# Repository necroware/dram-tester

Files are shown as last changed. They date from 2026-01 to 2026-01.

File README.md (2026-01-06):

# 4164 / 41256 DRAM Tester

This is a simple DRAM tester for 4164 and 41256 DRAM chips. It writes and reads
various patterns to verify the integrity of the memory chips. During the the
test red an green LEDs blink alternatively to indicate that the test is running.
If an error was detected, the the red LED will stay on permanently. If the chip
passed the test, the green LED will stay on. With JP1 closed, the tester will
expect a 4164 chip, with JP1 open, it will expect a 41256 chip.

## Why do we need this?

When working with vintage computers, it's common to encounter faulty DRAM chips.
This tester helps to quikly identify bad chips. There is no particular reason
why I decided to make this tester. There are already many similar designs, but
the ones I found were either too slow, or didn't work for me. So I decided to
learn a bit more about DRAMs and make my own tester which is fast and simple.

## Bill of Materials
- Arduino Nano or compatible board
- DIP-16 ZIF socket for 4164/41256 DRAM chips
- 2x 330 Ohm resistors (for LEDs)
- 2x LEDs (red and green)
- 22-100µF capacitor (for power supply stabilization)
- 2x1 2.54mm jumper (for JP1)

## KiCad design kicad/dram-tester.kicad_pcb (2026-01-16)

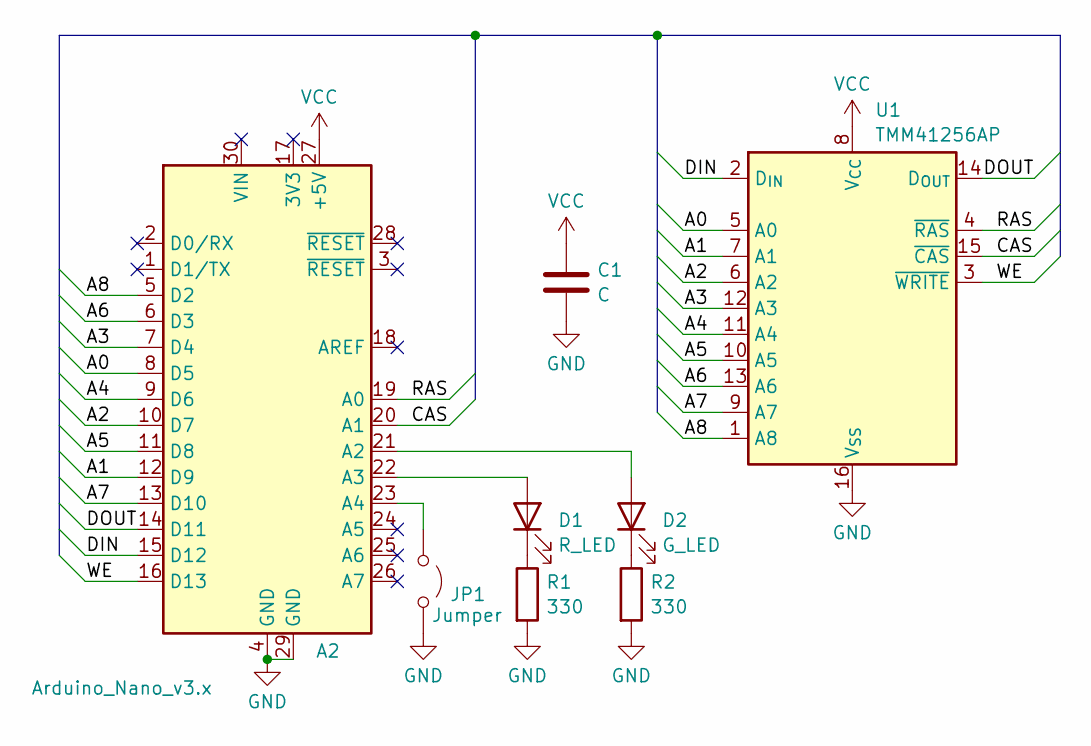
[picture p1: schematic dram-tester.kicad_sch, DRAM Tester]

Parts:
A2: Arduino_Nano_v3.x; Arduino_Nano
C1: C; C_Disc_D3.4mm_W2.1mm_P2.50mm
D1: R_LED; LED_D3.0mm
D2: G_LED; LED_D3.0mm
JP1: Jumper; PinHeader_1x02_P2.54mm_Vertical
R1, R2: 330; R_Axial_DIN0207_L6.3mm_D2.5mm_P10.16mm_Horizontal
U1: TMM41256AP; DIP_Socket-16_W4.3mm_W5.08mm_W7.62mm_W10.16mm_W10.9mm_3M_21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

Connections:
/A0: A2.8 (D5), U1.5 (A0)
/A1: A2.12 (D9), U1.7 (A1)
/A2: A2.10 (D7), U1.6 (A2)
/A3: A2.7 (D4), U1.12 (A3)
/A4: A2.9 (D6), U1.11 (A4)
/A5: A2.11 (D8), U1.10 (A5)
/A6: A2.6 (D3), U1.13 (A6)
/A7: A2.13 (D10), U1.9 (A7)
/A8: A2.5 (D2), U1.1 (A8)
/CAS: A2.20 (A1), U1.15 (~CAS)
/DIN: A2.15 (D12), U1.2 (D_{IN})
/DOUT: A2.14 (D11), U1.14 (D_{OUT})
/RAS: A2.19 (A0), U1.4 (~RAS)
/WE: A2.16 (D13), U1.3 (~WRITE)
GND: A2.4 (GND), A2.29 (GND), C1.2, JP1.2 (B), R1.2, R2.2, U1.16 (V_{SS})
unnamed: A2.21 (A2), D2.2 (A)
unnamed: A2.22 (A3), D1.2 (A)
unnamed: A2.23 (A4), JP1.1 (A)
unnamed: D1.1 (K), R1.1
unnamed: D2.1 (K), R2.1
VCC: A2.27 (+5V), C1.1, U1.8 (V_{CC})

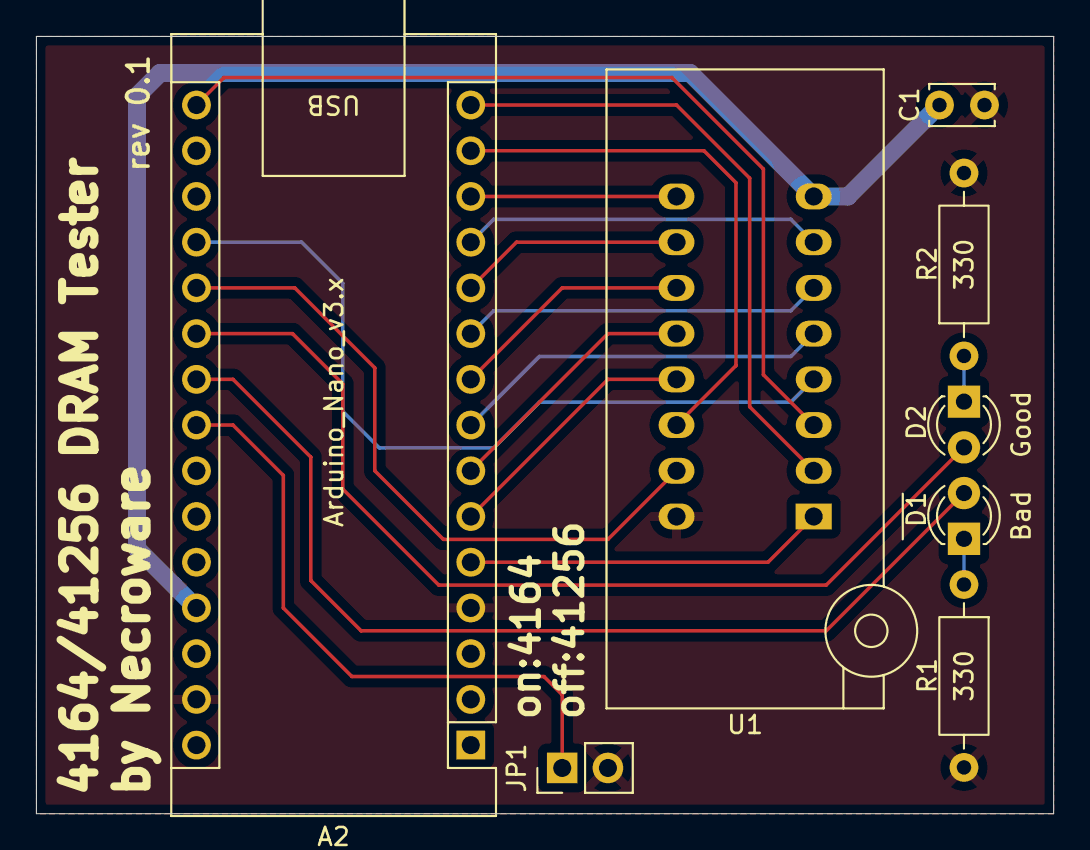
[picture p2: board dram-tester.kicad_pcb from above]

Board: 2 copper layers, 56.5 x 43.2 mm, 8 parts (0 on the bottom side), 21 nets.

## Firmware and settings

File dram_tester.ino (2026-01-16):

// 4164/41256 DRAM tester for Arduino Nano by Necroware
// License: CC-BY-SA-4.0

const uint8_t JP1 = A4;
const uint8_t G_LED = A2;
const uint8_t R_LED = A3;
const uint8_t PIN_RAS = A0;
const uint8_t PIN_CAS = A1;
const uint8_t PIN_WE = 13;
const uint8_t PIN_DO = 11;
const uint8_t PIN_DI = 12;

void set_address(uint16_t value) {
  value &= 0b111111111;
  PORTD = (PORTD & 0b00000011) | (value << 2);
  PORTB = (PORTB & 0b11111000) | (value >> 6);
}

void reset_pins() {
  digitalWrite(PIN_WE, HIGH);
  digitalWrite(PIN_CAS, HIGH);
  digitalWrite(PIN_RAS, HIGH);
}

void dram_write(int row, int col, int val) {
  set_address(row);
  digitalWrite(PIN_RAS, LOW);
  digitalWrite(PIN_WE, LOW);
  digitalWrite(PIN_DI, val);
  set_address(col);
  digitalWrite(PIN_CAS, LOW);
  digitalRead(PIN_DO);
  reset_pins();
}

int dram_read(int row, int col) {
  set_address(row);
  digitalWrite(PIN_RAS, LOW);
  set_address(col);
  digitalWrite(PIN_CAS, LOW);
  const auto val = digitalRead(PIN_DO);
  reset_pins();
  return val;
}

void set_leds(bool state) {
  digitalWrite(G_LED, state);
  digitalWrite(R_LED, !state);
}

template <typename T>
bool test(T&& generator) {
  const auto width = digitalRead(JP1) ? 64u : 256u;

  using operation_t = bool (*)(uint16_t, uint16_t, uint8_t);
  const auto iterate = [&](const operation_t& operation) {
    for (auto row = 0u; row < width; row++) {
      for (auto col = 0u; col < width; col++) {
        const auto pattern = generator(row, col) & 0x1;
        if (!operation(row, col, pattern)) {
          return false;
        }
      }
      // make it blink every 4th row
      if ((row & 0x3) == 0) {
        set_leds(row & 0x4);
      }
    }
    return true;
  };

  iterate([](uint16_t row, uint16_t col, uint8_t pattern) {
    dram_write(row, col, pattern);
    return true;
  });

  return iterate([](uint16_t row, uint16_t col, uint8_t pattern) {
    return dram_read(row, col) == pattern;
  });
}

void setup() {
  // Setup address pins
  DDRD |= 0b11111100;  // pins 2–7 as outputs
  DDRB |= 0b00000111;  // pins 8–10 as outputs

  pinMode(G_LED, OUTPUT);
  pinMode(R_LED, OUTPUT);
  pinMode(PIN_RAS, OUTPUT);
  pinMode(PIN_CAS, OUTPUT);
  pinMode(PIN_WE, OUTPUT);
  pinMode(PIN_DI, OUTPUT);
  pinMode(PIN_DO, INPUT);
  pinMode(JP1, INPUT_PULLUP);

  reset_pins();
}

void loop() {
  noInterrupts();
  set_leds(
      // checkmate
      test([](uint16_t row, uint16_t col) { return row + col; }) &&
      // inverted checkmate
      test([](uint16_t row, uint16_t col) { return ~(row + col); }) &&
      // all 1's
      test([](uint16_t row, uint16_t col) { return 1; }) &&
      // all 0's
      test([](uint16_t row, uint16_t col) { return 0; }));
  interrupts();

  while (true) {
    delay(1000);
  }
}

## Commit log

2026-01-16 minor fixes
    [dram-tester.kicad_pcb, dram-tester.kicad_sch]
2026-01-16 add logos
    [dram-tester.kicad_pcb]
2026-01-16 fix A8 trace
    [dram-tester.kicad_pcb, dram-tester.kicad_sch]
